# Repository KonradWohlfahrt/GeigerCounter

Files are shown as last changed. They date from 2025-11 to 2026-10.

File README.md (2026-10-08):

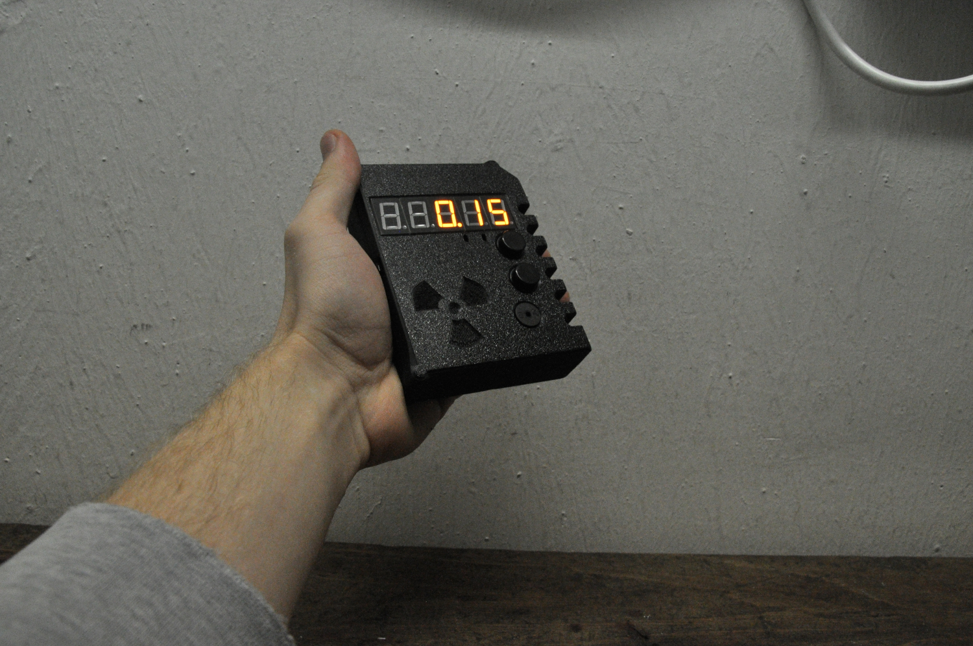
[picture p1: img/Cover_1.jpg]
Cover


# DIY Geiger Counter
This project is a fully functional DIY Geiger counter built around an M4011 Geiger–Müller tube, a custom two-board PCB design, and a retro-style five-digit seven-segment display. It’s portable, battery-powered and easy to build yourself.
The device measures radiation in µS/h, cpm, and raw counts, with settings stored in EEPROM. Navigation is handled by two buttons, and the counter provides both visual and audible feedback for detected radiation pulses. The project includes a 3D-printed housing with optional decorative elements.  
All PCBs and the stencil for this project were fabricated by [PCBWay](https://www.pcbway.com/), whose quality and service helped make the build smooth and enjoyable.  
This repository includes schematics, PCB files, firmware, STL files, and documentation so you can build your own portable Geiger Counter from scratch. You can find the full blog on Instructables: [DIY Geiger Counter](https://www.instructables.com/DIY-Geiger-Counter/)

**NOTE:**  
Version 3 of the main PCB is planned to address low-voltage limitations of the MT3608 boost converter. Version 2 users are encouraged to add a 100 µF capacitor across 5V and GND for improved stability.

***
# FEATURES
- Detects radiation using an M4011 Geiger-Müller tube
- Displays measurements in µS/h, cpm, or counts
- Simple navigation using two buttons: switch modes, reset counts, and access settings
- Configurable options saved in EEPROM: battery type, sound, and LED indicators
- Retro-inspired five-digit seven-segment display powered by two AA batteries

***
# PROGRAMMING
Programmed with the Arduino IDE and [MiniCore board manager](https://mcudude.github.io/MiniCore/package_MCUdude_MiniCore_index.json). No external library is required, everything is included in the sketch!

***
# ELECTRIC COMPONENTS - HIGH VOLTAGE CIRCUIT:
| Component | Amount | Silkscreen label |
|:---|:---:|---:|
| 1nF | 1 | C1 |
| 10nF | 2 | C2,C3 |
| 220pF | 2 | C4,C5 |
| 1N914 | 1 | D1 |
| 1N4937 | 1 | D2 |
| 5x20 Fuse Clip | 2 | J1-J4 |
| 5P-2.54 Header | 2 | J5,J6 |
| 10mH Inductor | 1 | L1 |
| 2N3904 | 2 | Q1,Q3 |
| FJN3303 | 1 | Q2 |
| 220k | 1 | R1 |
| 1k | 1 | R2 |
| 330r | 1 | R3 |
| 100k | 2 | R4,R9 |
| 8.2r | 1 | R5 |
| 10r potentiometer | 1 | R6 |
| 4.7M | 1 | R7 |
| 22k | 1 | R8 |
| 10k | 1 | R10 |
| TLC555 | 1 | U1 |
| M4011/J302/SI-3BG | 1 | - |

***
# ELECTRIC COMPONENTS - MAIN BOARD V3 CIRCUIT:
| Component | Amount | Silkscreen label |
|:---|:---:|---:|
| BH-AA-A5BJ012 | 2 | B1,B2 |
| Passive Buzzer 12x9.5 | 1 | BUZ1 |
| 22uF 0805 | 2 | C1,C2 |
| 100nF 0805 | 8 | C3-C6,C11-C13,C18 |
| 22pF 0805 | 2 | C7,C8 |
| 10uF 0805 | 1 | C9 |
| 1uF 0805 | 2 | C10,C17 |
| 100pF 0805 | 2 | C14,C15 |
| 100uF 1206 | 1 | C16 |
| 6P (2x3) 2.54 ICSP Header (optional) | 1 | H1 |
| 5P-2.54 Header | 2 | H3,H4 |
| Switch 12x12 & Round Button Cover | 2 | KEY1,KEY2 |
| 4.7uH 3015 | 1 | L1 |
| 5161BY Seven Segment Digit | 5 | LED1-LED5 |
| 0805 LED red | 2 | LED6,LED8 |
| 0805 LED green | 1 | LED7 |
| MMBT2222A | 3 | Q1-Q3 |
| 976k | 1 | R1 |
| 309k | 1 | R2 |
| 10k | 3 | R3,R9,R10 |
| 220r | 3 | R4,R12,R14 |
| 1k | 3 | R5,R11,R13 |
| 33r | 1 | R6 |
| 1.2k | 1 | R7 |
| 680r | 1 | R8 |
| SKF14L3 | 1 | SW1 |
| Switch SMD 3x6 | 1 | SW2 |
| MCP1640CT SOT-23-6 | 1 | U1 |
| ATmega328P | 1 | U2 |
| TM1637 | 1 | U3 |
| 8Mhz/16Mhz 3225 crystal | 1 | X1 |

***
# ELECTRIC COMPONENTS - MAIN BOARD V2 CIRCUIT:
| Component | Amount | Silkscreen label |
|:---|:---:|---:|
| BH-AA-A5BJ012 | 2 | B1,B2 |
| Passive Buzzer 12x9.5 | 1 | BUZ1 |
| 22uF | 2 | C1,C2 |
| 100nF | 6 | C3-C5,C10-C12 |
| 22pF | 2 | C6,C7 |
| 10uF | 1 | C8 |
| 1uF | 1 | C9 |
| 100pF | 2 | C13,C14 |
| SS34 | 1 | D1 |
| 6P (2x3) 2.54 ICSP Header (optional) | 1 | H1 |
| 5P-2.54 Header | 2 | H3,H4 |
| Switch 12x12 & Round Button Cover | 2 | KEY1,KEY2 |
| 22uH | 1 | L1 |
| 5161BY Seven Segment Digit | 5 | LED1-LED5 |
| 0805 LED red | 2 | LED6,LED8 |
| 0805 LED green | 1 | LED7 |
| MMBT2222A | 3 | Q1-Q3 |
| 220k | 1 | R1 |
| 30k | 1 | R2 |
| 10k | 3 | R3,R9,R10 |
| 220r | 3 | R4,R12,R14 |
| 1k | 3 | R5,R11,R13 |
| 33r | 1 | R6 |
| 1.2k | 1 | R7 |
| 680r | 1 | R8 |
| SKF14L3 | 1 | SW1 |
| Switch SMD 3x6 | 1 | SW2 |
| MT3608 | 1 | U1 |
| ATmega328P | 1 | U2 |
| TM1637 | 1 | U3 |
| 8Mhz/16Mhz 3225 crystal | 1 | X1 |

***
# Housing Components:
| Component | Amount |
|:---|---:|
| M3 Threaded Heat Insert: 5x4,2mm (height x outer diameter) | 8 |
| M3x6mm | 2 |
| M3x18mm | 3 |
| M3x20mm | 3 |
| M3 Threaded Heat Insert: 3x4,2mm (height x outer diameter) | 1 |
| M3x4mm | 1 |
| AA Battery | 2 |

***
# GALLERY
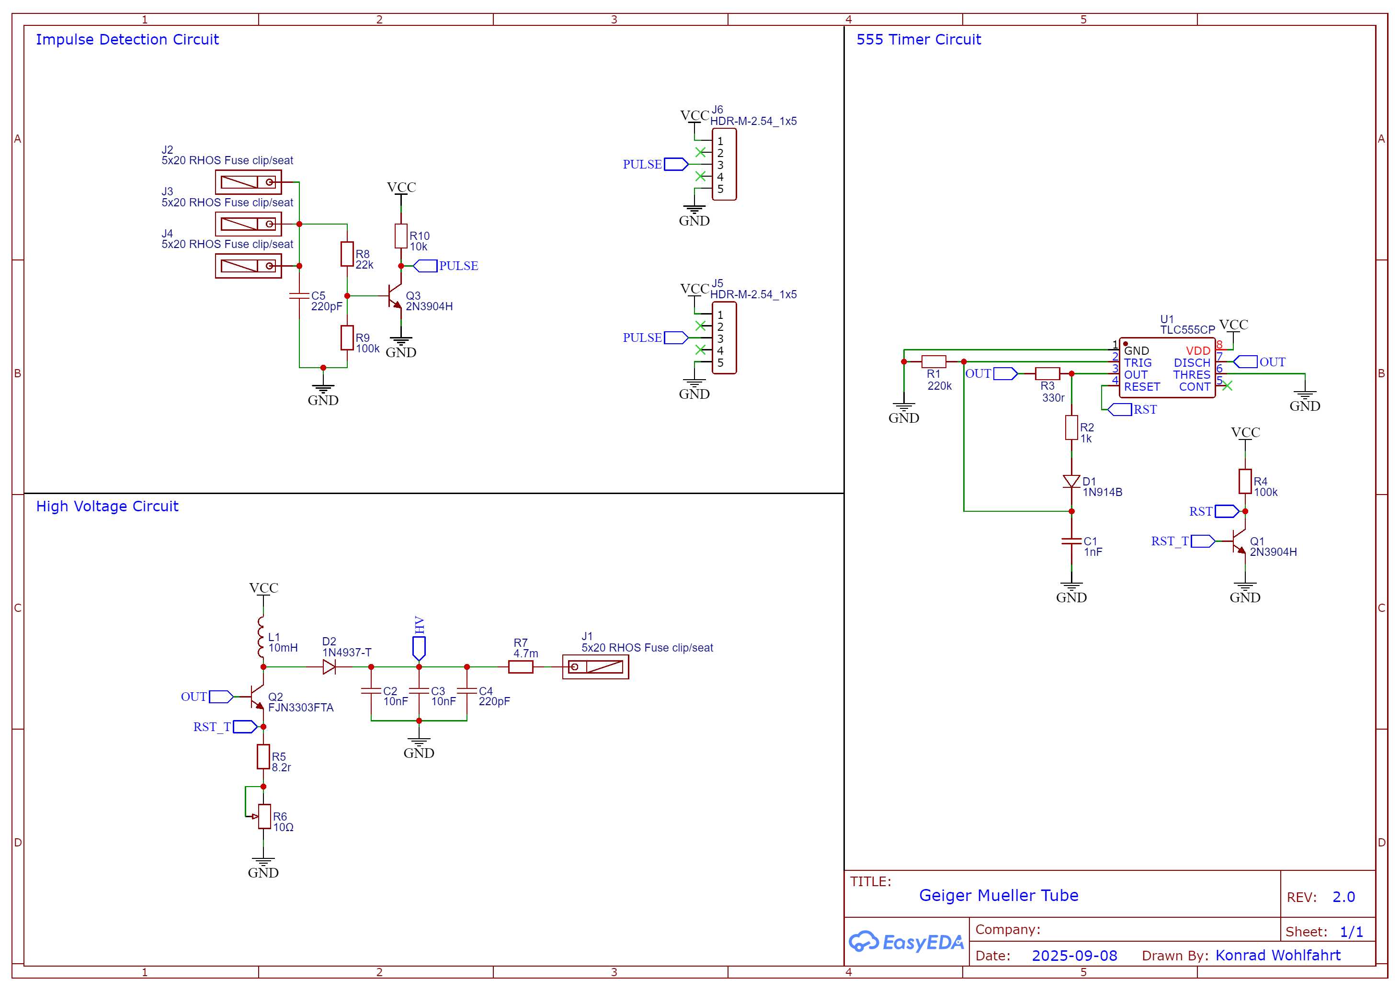
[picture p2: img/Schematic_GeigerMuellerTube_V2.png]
Schematic HV Circuit

_Schematic of the high voltage PCB_  
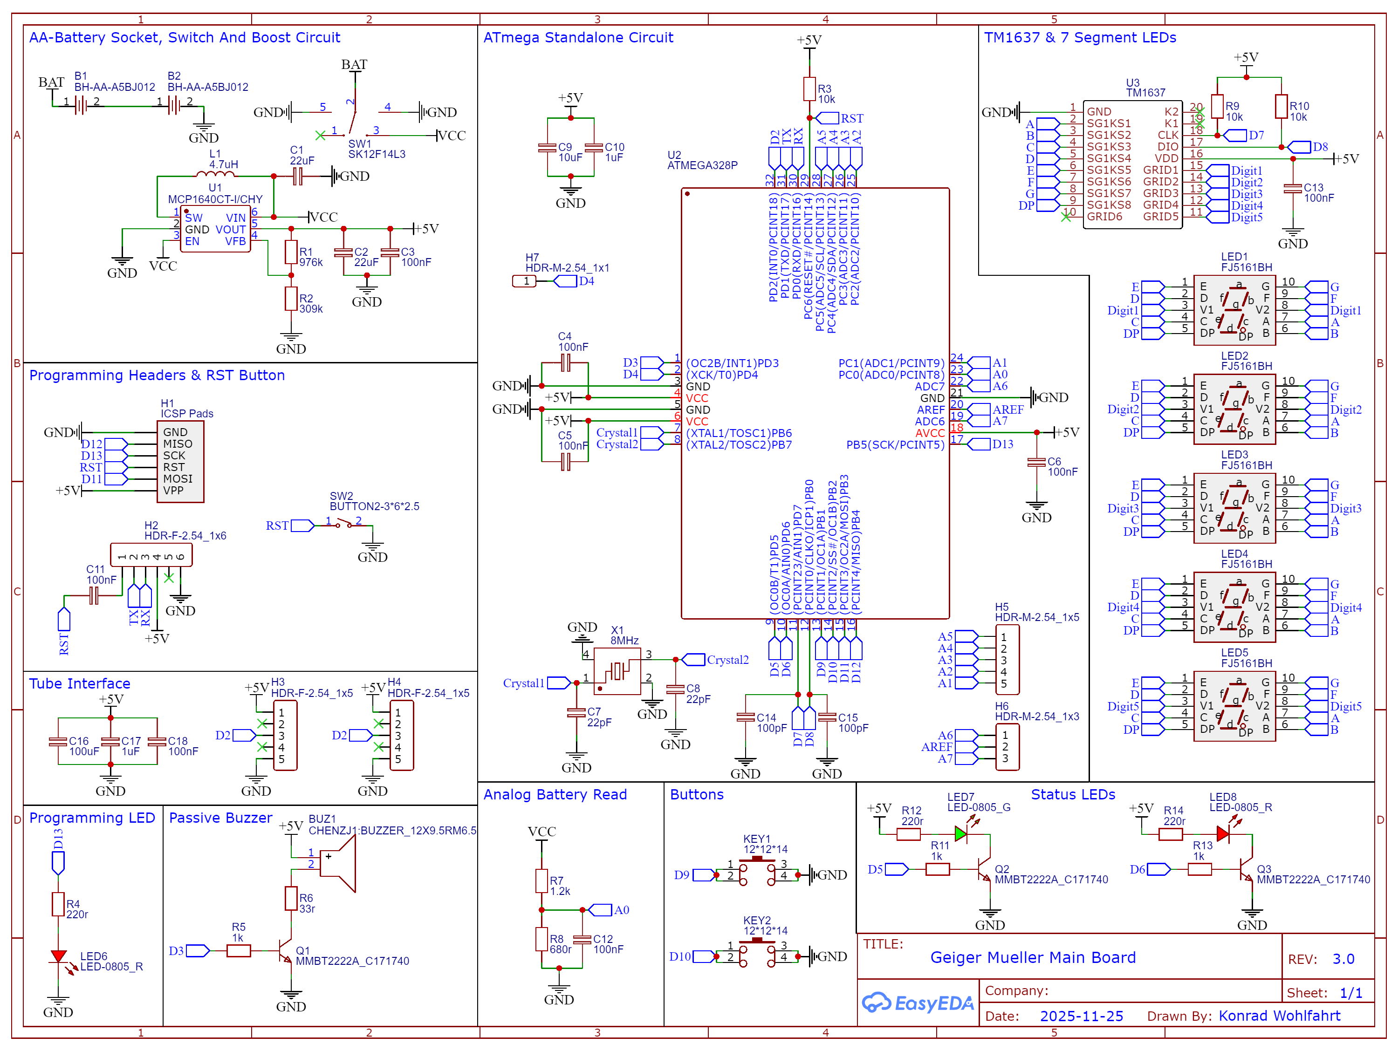
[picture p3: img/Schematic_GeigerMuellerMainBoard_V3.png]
Schematic MainBoard

_Schematic of the main board (V3)_  
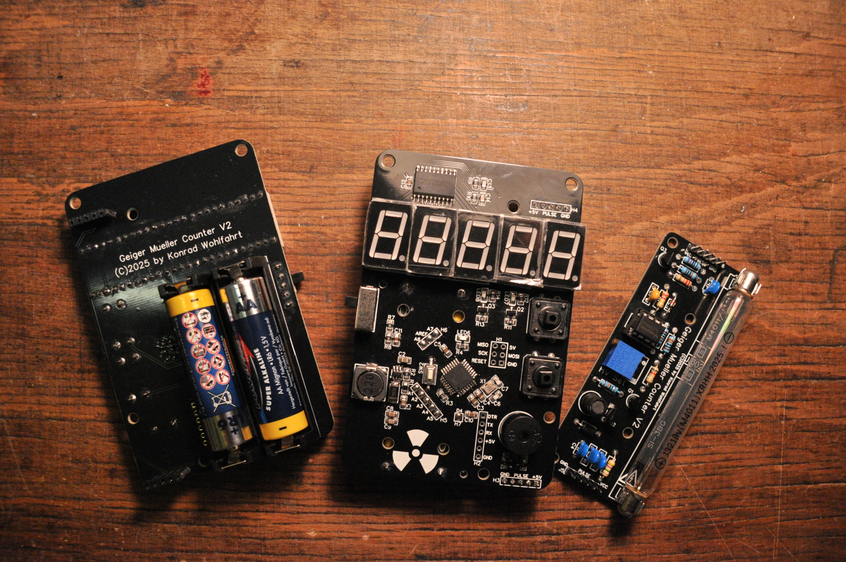
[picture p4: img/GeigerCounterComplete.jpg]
Complete Geiger Counter

_Complete Geiger Counter Build_  
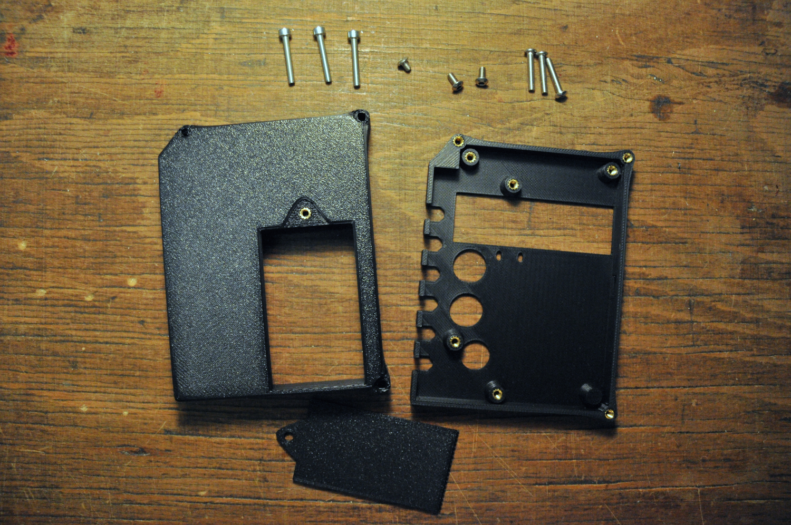
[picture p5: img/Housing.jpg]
Housing

_3D printed housing_  

***
# NAVIGATION
The Geiger counter is controlled with two buttons. The **lower button** cycles through the measurement modes: µS/h (microsieverts per hour), cpm (counts per minute), and total counts. The **upper button** resets the counts to zero, which also restarts the µS/h and cpm readings. Holding down the **upper button** takes you into the settings menu. Once inside, the **lower button** cycles through the available options, while the **upper button** changes the selected setting. A long press exits the menu and returns to the main display.  
The configurable options include battery type (Alkaline, NiMH, or Lithium), sound (On or Off), and LED indicators (On or Off — the warning LED always remains on). All settings are saved in EEPROM, so they remain even after the counter is powered off.  

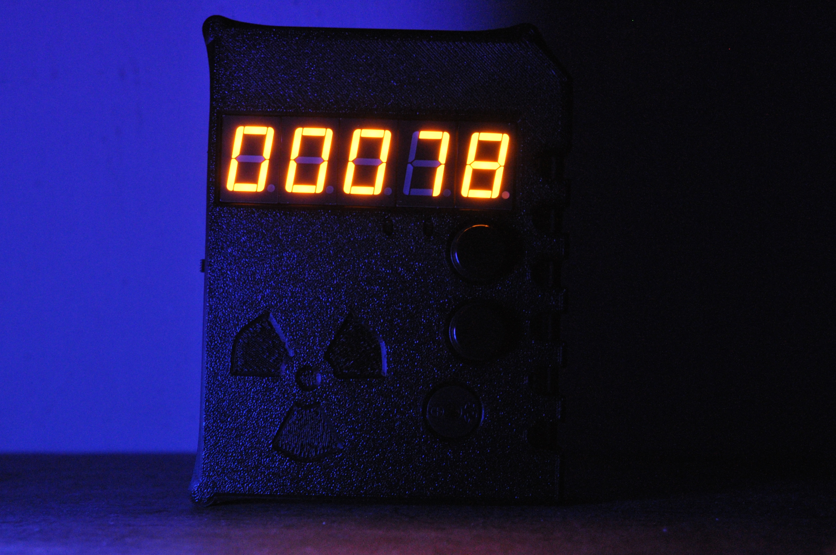
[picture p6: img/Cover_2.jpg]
Geiger Counter


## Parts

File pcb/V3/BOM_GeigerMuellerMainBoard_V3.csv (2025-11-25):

ID | Name | Designator | Footprint | Quantity | Manufacturer Part | Manufacturer | Supplier | Supplier Part | Price | Pins | 3DModel | Contributor | JLCPCB Part Class | image | link
1 | BH-AA-A5BJ012 | B1,B2 | BAT-TH_BH-AA-A5BJ012 | 2 | BH-AA-A5BJ012 | MYOUNG(美阳) | LCSC | C5290180 | 0.576 | 2 | BAT-TH_BH-AA-A5BJ012 | lcsc | Extended Part |  | https://atta.szlcsc.com/upload/public/pdf/source/20221129/39BBE9EF152B2F12CD5AEA2F9E97207C.pdf
2 | MCP1640CT-I/CHY | U1 | SOT-23-6_L2.9-W1.6-P0.95-LS2.8-BR | 1 | MCP1640CT-I/CHY | MICROCHIP(美国微芯) | LCSC | C511326 | 0.815 | 6 | SOT-23-6_L2.9-W1.6-H1.5-LS2.8-P0.95 | LCSC | Extended Part |  | https://item.szlcsc.com/169042.html
3 | 309k | R2 | R0805 | 1 |  |  |  |  |  | 2 | R0805_L2.0-W1.3-H0.6 | LCEDA_Lib |  |  | https://item.szlcsc.com/142685.html
4 | 976k | R1 | R0805 | 1 |  |  |  |  |  | 2 | R0805_L2.0-W1.3-H0.6 | LCEDA_Lib |  |  | https://item.szlcsc.com/142685.html
5 | 4.7uH | L1 | IND-SMD_L3.0-W3.0-1 | 1 | ANR3015T4R7M | APV(爱普微) | LCSC | C7427089 | 0.034 | 2 | IND-SMD_L3.0-W3.0-1 | lcsc | Extended Part |  | https://atta.szlcsc.com/upload/public/pdf/source/20210916/41BC1D61F1B8031533859732D09FE353.pdf
6 | 100uF | C16 | C1206 | 1 |  |  |  |  |  | 2 | C1206_L3.2-W1.6-H1.3 | LCEDA_Lib |  |  | https://item.szlcsc.com/89171.html
7 | 100nF | C18,C3,C4,C5,C6,C11,C12,C13 | C0805 | 8 |  |  |  |  |  | 2 | C0805_L2.0-W1.3-H1.3 | LCEDA_Lib |  |  | https://item.szlcsc.com/373011.html
8 | 1uF | C17,C10 | C0805 | 2 |  |  |  |  |  | 2 | C0805_L2.0-W1.3-H1.3 | LCEDA_Lib |  |  | https://item.szlcsc.com/373011.html
9 | 22uF | C2,C1 | C0805 | 2 |  |  |  |  |  | 2 | C0805_L2.0-W1.3-H1.3 | LCEDA_Lib |  |  | https://item.szlcsc.com/373011.html
10 | CHENZJ1:BUZZER_12X9.5RM6.5 | BUZ1 | BUZ-TH_BD12.0-P6.50-D0.6_SEA-1285F | 1 | chenzj1:Buzzer_12x9.5RM6.5 | null | LCSC | C9900008742 |  | 2 | BUZ-TH_BD12.0-P6.50-D0.6_SEA-1285F | LCSC | Extended Part |  | https://atta.szlcsc.com/upload/public/pdf/source/20211008/4CBF24C00656D781101954279FAE3DDF.pdf
11 | 22pF | C7,C8 | C0805 | 2 |  |  |  |  |  | 2 | C0805_L2.0-W1.3-H1.3 | LCEDA_Lib |  |  | https://item.szlcsc.com/373011.html
12 | 10uF | C9 | C0805 | 1 |  |  |  |  |  | 2 | C0805_L2.0-W1.3-H1.3 | LCEDA_Lib |  |  | https://item.szlcsc.com/373011.html
13 | 100pF | C14,C15 | C0805 | 2 |  |  |  |  |  | 2 | C0805_L2.0-W1.3-H1.3 | LCEDA_Lib |  |  | https://item.szlcsc.com/373011.html
14 | ICSP Pads | H1 | ICSP | 1 |  |  |  |  |  | 6 |  | dreAn
15 | HDR-F-2.54_1x6 | H2 | HDR-F-2.54_1X6 | 1 |  |  | LCSC | C40877 | 0.071 | 6 | HDR-F-2.54_1x6 | LCEDA_Lib
16 | HDR-F-2.54_1x5 | H3,H4 | HDR-F-2.54_1X5 | 2 |  |  | LCSC | C50950 | 0.064 | 5 | HDR-F-2.54_1x5 | LCEDA_Lib
17 | HDR-M-2.54_1x5 | H5 | HDR-M-2.54_1X5 | 1 |  |  | LCSC | C358687 | 0.03 | 5 | HDR-M-2.54_1x5 | LCEDA_Lib
18 | HDR-M-2.54_1x3 | H6 | HDR-M-2.54_1X3 | 1 |  |  | LCSC | C180248 | 0.187 | 3 | HDR-M-2.54_1x3 | LCEDA_Lib
19 | HDR-M-2.54_1x1 | H7 | HDR-M-2.54_1X1 | 1 |  |  | LCSC | C81276 | 0.008 | 1 | HDR-M-2.54_1x1 | LCEDA_Lib
20 | 12*12*14 | KEY1,KEY2 | SW-TH_4P-L12.0-W12.0-P5.00-LS12.5_TC-1103XX | 2 | 12*12*14 | ReliaPro | LCSC | C27480 |  | 4 | SW-TH_4P-L12.0-W12.0-P5.00-LS12.5_TC-1103XX | lcsc | Extended Part |  | https://item.szlcsc.com/487764.html?ref=editor&logined=true
21 | FJ5161BH | LED1,LED2,LED3,LED4,LED5 | LED-SEG-TH_FJ5161BH | 5 | FJ5161BH | 志浩 | LCSC | C8092 | 0.199 | 10 | LED-SEG-TH_10P-L12.6-W19.0-H8.0-P2.54-S15.24 | 立创EDA官方封装库 | Extended Part |  | https://item.szlcsc.com/8574.html
22 | LED-0805_R | LED6,LED8 | LED0805_RED | 2 | 17-21SURC/S530-A3/TR8 | EVERLIGHT(台湾亿光) |  | C72037 | 0.025 | 2 | LED0805_Red | LCEDA_Lib
23 | LED-0805_G | LED7 | LED0805_GREEN | 1 | NCD0805G1 | 国星光电 |  | C84260 | 0.02 | 2 | LED0805_Green | LCEDA_Lib
24 | MMBT2222A_C171740 | Q1,Q2,Q3 | SOT-23-3_L2.9-W1.3-P1.90-LS2.4-BR | 3 | MMBT2222A | SHIKUES(时科) | LCSC | C171740 | 0.013 | 3 | SOT-23-3P_L2.9-W1.3-H1.0-LS2.4-P0.95 | 立创EDA官方封装库 | Extended Part |  | https://www.diodes.com/assets/Package-Files/SOT23.pdf
25 | 10k | R3,R9,R10 | R0805 | 3 |  |  |  |  |  | 2 | R0805_L2.0-W1.3-H0.6 | LCEDA_Lib |  |  | https://item.szlcsc.com/142685.html
26 | 220r | R4,R12,R14 | R0805 | 3 |  |  |  |  |  | 2 | R0805_L2.0-W1.3-H0.6 | LCEDA_Lib |  |  | https://item.szlcsc.com/142685.html
27 | 1k | R5,R11,R13 | R0805 | 3 |  |  |  |  |  | 2 | R0805_L2.0-W1.3-H0.6 | LCEDA_Lib |  |  | https://item.szlcsc.com/142685.html
28 | 100r | R6 | R0805 | 1 |  |  |  |  |  | 2 | R0805_L2.0-W1.3-H0.6 | LCEDA_Lib |  |  | https://item.szlcsc.com/142685.html
29 | 1.2k | R7 | R0805 | 1 |  |  |  |  |  | 2 | R0805_L2.0-W1.3-H0.6 | LCEDA_Lib |  |  | https://item.szlcsc.com/142685.html
30 | 680r | R8 | R0805 | 1 |  |  |  |  |  | 2 | R0805_L2.0-W1.3-H0.6 | LCEDA_Lib |  |  | https://item.szlcsc.com/142685.html
31 | SK12F14L3 | SW1 | SW-TH_SK12F14G5 | 1 | SK12F14L3 | XKB Connection(中国星坤) | LCSC | C5146272 | 0.026 | 5 | SW-TH_SK12F14G5 | lcsc |  |  | https://atta.szlcsc.com/upload/public/pdf/source/20210820/9527CA5F223E7A23E59122DED0FC191C.pdf
32 | BUTTON2-3*6*2.5 | SW2 | SW-SMD_L6.0-W3.7-LS8.0 | 1 | BUTTON2-3*6*2.5 | null | LCSC | C9900009018 |  | 2 | SW-SMD_L6.0-W3.7-LS8.0 | LCSC | Extended Part |  | https://item.szlcsc.com/1054610.html
33 | ATMEGA328P | U2 | LQFP-32_L7.0-W7.0-P0.80-LS9.0-TL | 1 | ATmega328P | null | LCSC | C9900009806 |  | 32 | LQFP-32_L7.0-W7.0-H1.4-LS9.0-P0.80 | LCSC | Extended Part |  | https://item.szlcsc.com/179025.html
34 | TM1637 | U3 | SOP-20_L12.8-W7.5-P1.27-LS10.4-BL | 1 | TM1637 | TM(天微) | LCSC | C20001 | 0.217 | 20 | SOP-20_L12.8-W7.5-H2.5-LS10.4-P1.27 | Tinkerforge | Extended Part |  | https://item.szlcsc.com/365354.html
35 | 8MHz | X1 | CRYSTAL-SMD_4P-L3.2-W2.5-BL | 1 | L327S080D11L | Lucki(蓝晶) | LCSC | C5261255 | 0.151 | 4 | CRYSTAL-SMD_4P-L3.2-W2.5-BL | lcsc | Extended Part |  | https://item.szlcsc.com/15866.html

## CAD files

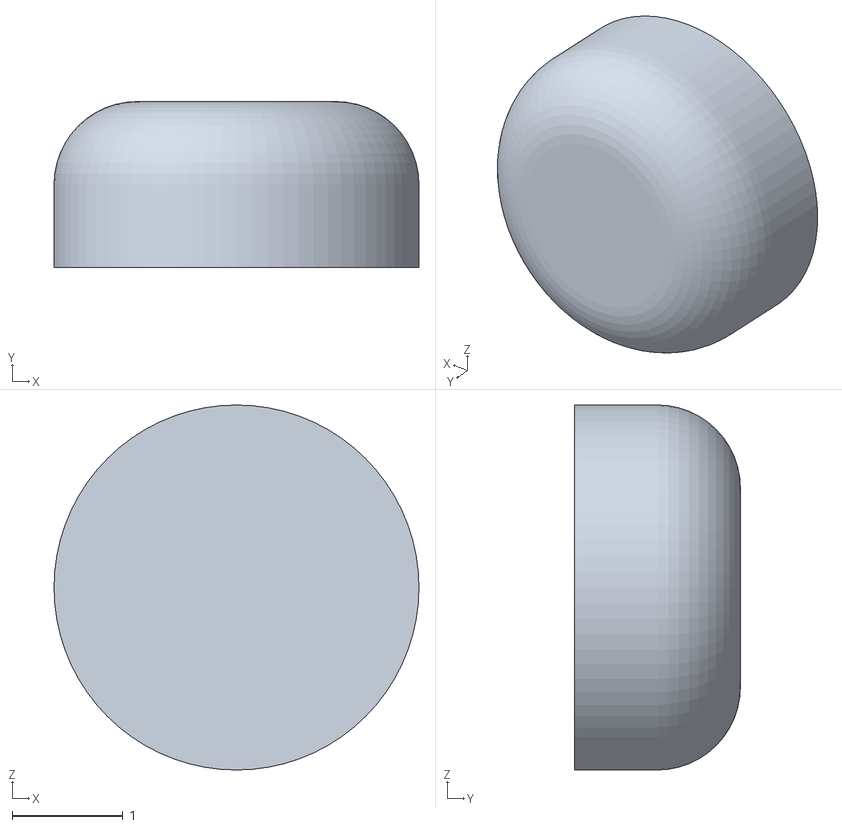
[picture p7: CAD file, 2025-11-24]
cad/RadioactiveSignInner.stl
3.30 x 1.50 x 3.30

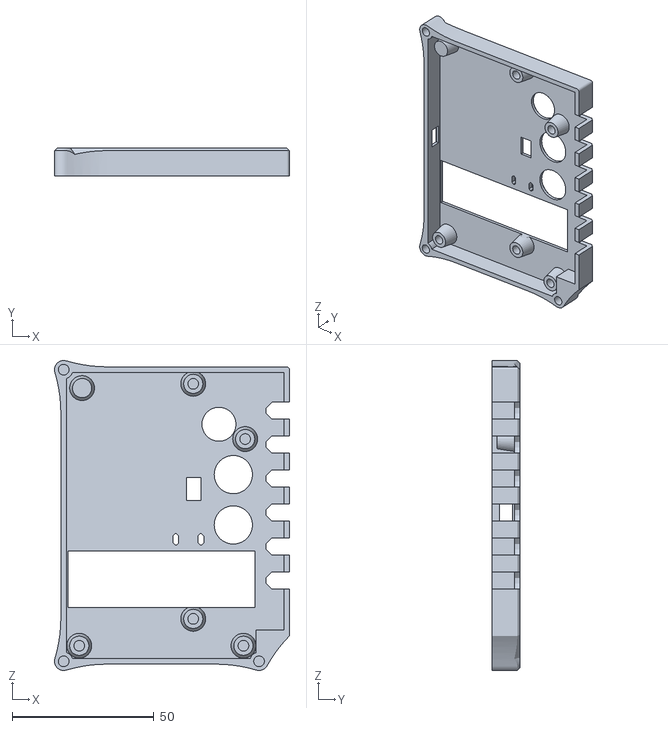
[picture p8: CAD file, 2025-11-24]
cad/Geiger Counter Top.stl
83.0 x 10.0 x 109.5

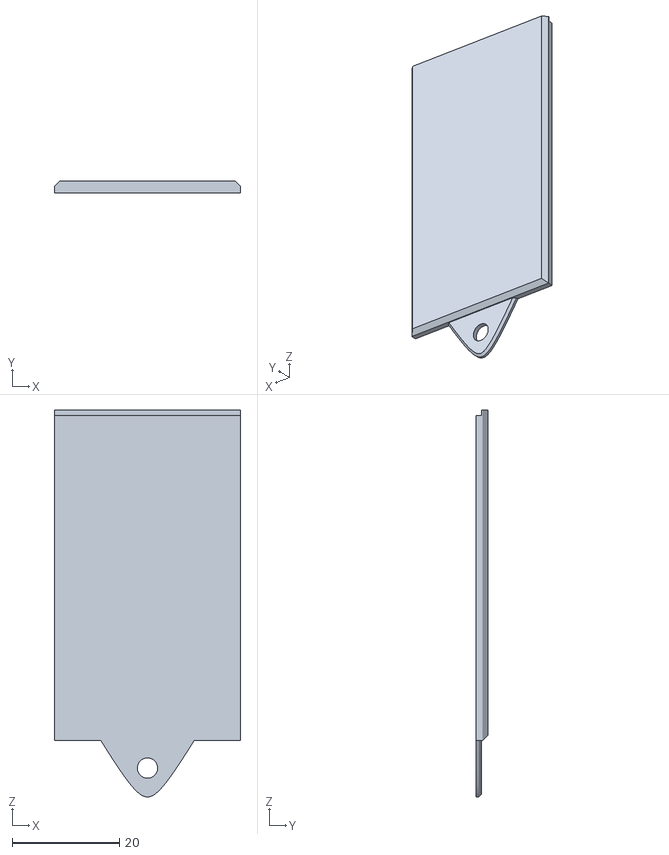
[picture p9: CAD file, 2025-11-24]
cad/Geiger Counter Battery Lid.stl
34.8 x 2.20 x 72.3

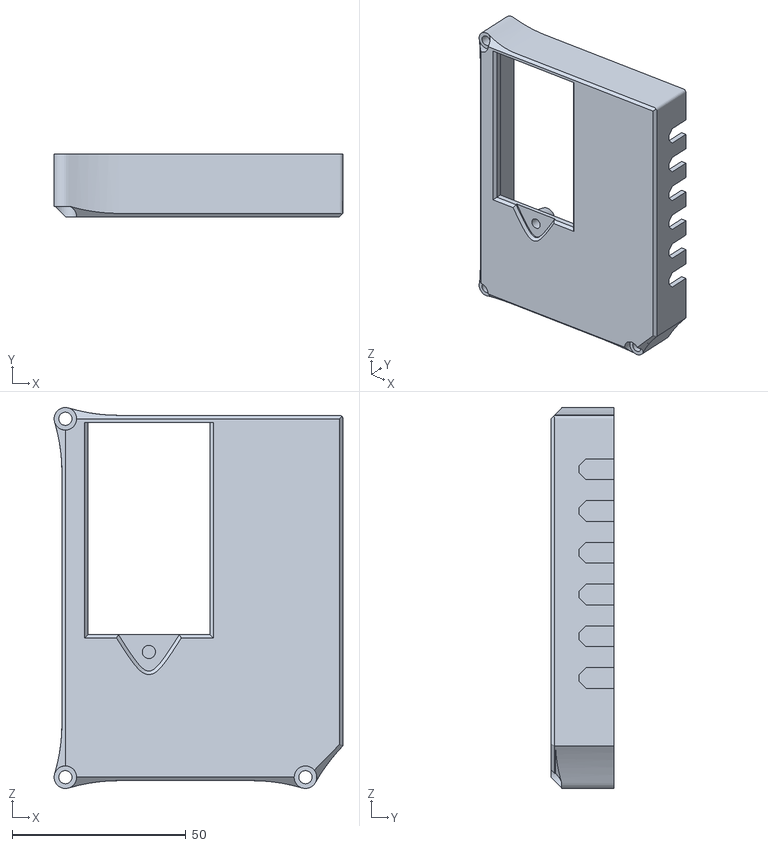
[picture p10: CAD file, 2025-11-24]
cad/Geiger Counter Bottom.stl
83.0 x 18.0 x 109.5

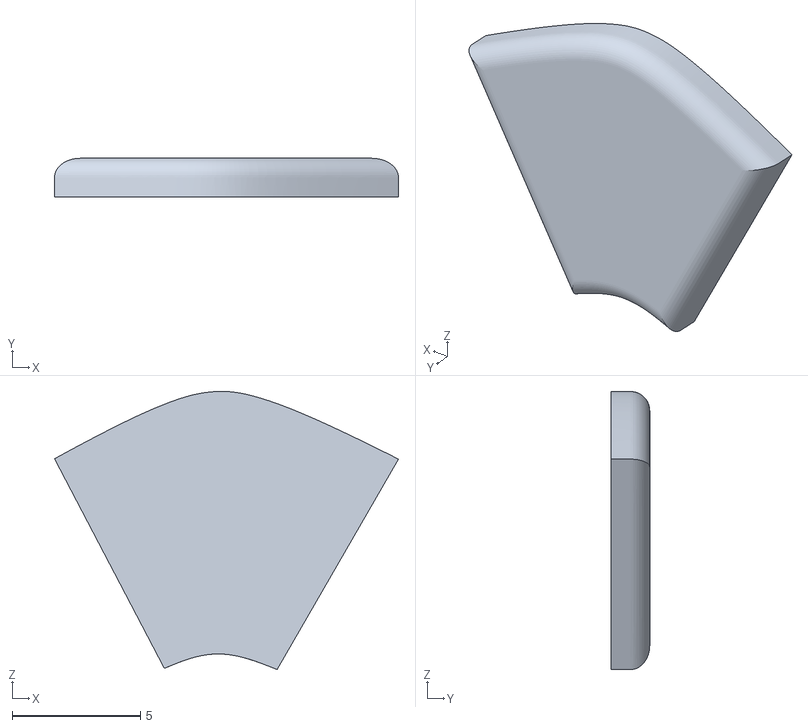
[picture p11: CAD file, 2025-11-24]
cad/RadioactiveSignOuter.stl
13.4 x 1.50 x 10.8

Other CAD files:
cad/Geiger Counter Top without ICSP.stl

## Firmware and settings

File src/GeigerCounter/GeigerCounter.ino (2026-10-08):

#include "preferences.h"

volatile bool pulseEvent = false;
volatile uint32_t counts = 0;
uint32_t resetTimestamp = 0;
float cpm;
float uSievert;

uint32_t infoTimestamp;
bool showInfo = false;

uint32_t lastRefresh;
uint8_t displayIndex = 2; // 0=uS/h, 1=cpm, 2=total counts (will select next mode at start)

bool settings = false;
uint8_t settingsIndex = 0; // 0=battery, 1=sound, 2=leds
bool hasSound = true;
bool ledsOn = true;
const char batteryChars[3][5] = {
  { 'a', 'l', 'k', 'a', 'l' },
  { 'n', 'i', 'm', 'h', 0 },
  { 'l', 'i', 't', 'h', 'i' }
};


void setup() 
{
  // set up pins
  analogReference(INTERNAL);
  pinMode(BATTERY_PIN, INPUT);

  pinMode(PULSE_PIN, INPUT);

  pinMode(BUTTON_UP, INPUT_PULLUP);
  pinMode(BUTTON_DOWN, INPUT_PULLUP);

  pinMode(BUZZER_PIN, OUTPUT);

  pinMode(LED_RED, OUTPUT);
  pinMode(LED_GREEN, OUTPUT);

  // show boot animation, set voltage stabilize
  display.clear();
  display.setInt(88888); // all segments on
  for (uint8_t i = 0; i < 8; i++)
  {
    analogWrite(LED_RED, 255 / 8 * i);
    analogWrite(LED_GREEN, 255 / 8 * i);

    display.setBrightness(i);
    display.show();
    delay(50);
  }
  analogWrite(LED_RED, 0);
  analogWrite(LED_GREEN, 0);

  // read EEPROM
  _selectedBattery = constrain(EEPROM.read(0), 0, 2);
  hasSound = constrain(EEPROM.read(1), 0, 1);
  ledsOn = constrain(EEPROM.read(2), 0, 1);

  // show battery voltage at start
  updateBrightness();
  display.setInt(batteryPercent(), true);
  display.move(2);
  display.setDigit(4, 0b00011011);
  display.show();
  delay(2000);

  resetCounts();
  nextMode();

  attachInterrupt(digitalPinToInterrupt(PULSE_PIN), pulseInterrupt, FALLING);
}
void loop() 
{
  if (btnUp())
  {
    uint32_t started = millis();
    bool longPress = false;
    while (btnUp())
    {
      updateScreen(false);
      if (!longPress && isTimestamp(started, LONG_PRESS))
      {
        longPress = true;
        settings = !settings;
        settingsIndex = 0;
      }
    }
    
    if (!longPress)
    {
      if (settings)
      {
        if (settingsIndex == 0)
          _selectedBattery = (_selectedBattery + 1) % 3;
        else if (settingsIndex == 1)
          hasSound = !hasSound;
        else
          ledsOn = !ledsOn;
      }
      else
        resetCounts();
    }
    else if (!settings)
      saveEEPROM();
    updateScreen(true);
  }

  if (btnDown())
  {
    while (btnDown()) updateScreen(false);
    
    nextMode();
    updateScreen(true);
  }

  if (showInfo && isTimestamp(infoTimestamp, 750))
  {
    showInfo = false;
    updateScreen(true);
  }
  else
    updateScreen(false);
}

void pulseInterrupt() 
{
  counts++;
  pulseEvent = true;
  if (hasSound)
    click();
}
void updateScreen(bool force)
{
  updateWarnLED();

  if (settings)
  {
    display.clear();
    if (settingsIndex == 0)
    {
      for (uint8_t i = 0; i < 5; i++)
        display.setDigit(i, display.getCharacter(batteryChars[_selectedBattery][i]));
    }
    else if (settingsIndex == 1)
    {
      display.setDigit(0, display.getNumber(5));
      if (hasSound)
      {
        display.setDigit(3, display.getCharacter('o'));
        display.setDigit(4, display.getCharacter('n'));
      }
      else
      {
        display.setDigit(2, display.getCharacter('o'));
        display.setDigit(3, display.getCharacter('f'));
        display.setDigit(4, display.getCharacter('f'));
      }
    }
    else
    {
      display.setDigit(0, display.getCharacter('l'));
      if (ledsOn)
      {
        display.setDigit(3, display.getCharacter('o'));
        display.setDigit(4, display.getCharacter('n'));
      }
      else
      {
        display.setDigit(2, display.getCharacter('o'));
        display.setDigit(3, display.getCharacter('f'));
        display.setDigit(4, display.getCharacter('f'));
      }
    }
    display.show();
    return;
  }

  if (showInfo)
  {
    display.clear();
    if (displayIndex == 0)
    {
      display.setDigit(0, display.getCharacter('u'));
      display.setDigit(1, display.getCharacter('5'));
      display.setDigit(2, display.getCharacter('/'));
      display.setDigit(3, display.getCharacter('h'));
    }
    else if (displayIndex == 1)
    {
      display.setDigit(0, display.getCharacter('c'));
      display.setDigit(1, display.getCharacter('p'));
      display.setDigit(2, display.getCharacter('m'));
    }
    else if (displayIndex == 2)
    {
      display.setDigit(0, display.getCharacter('c'));
      display.setDigit(1, display.getCharacter('o'));
      display.setDigit(2, display.getCharacter('u'));
      display.setDigit(3, display.getCharacter('n'));
      display.setDigit(4, display.getCharacter('t'));
    }
    display.show();
  }
  else
  {
    if (pulseEvent || force || isTimestamp(lastRefresh, 1000))
    {
      pulseEvent = false;
      cpm = counts / ((millis() - resetTimestamp) / 60000.0f);
      uSievert = cpm / TUBE_FACTOR;
      
      updateBrightness();
      if (displayIndex == 0)
        display.setFloat(uSievert);
      else if (displayIndex == 1)
        display.setFloat(cpm);
      else if (displayIndex == 2)
        display.setInt(counts % 100000, true);
      display.show();
    }
  }
}
void updateWarnLED()
{
  if (uSievert < 0.5f || (uSievert < 2.5f && !ledsOn))
  {
    analogWrite(LED_GREEN, 0);
    analogWrite(LED_RED, 0);
  }
  else if (uSievert < 1.0f && ledsOn)
  {
    analogWrite(LED_GREEN, 80);
    analogWrite(LED_RED, 0);
  }
  else if (uSievert < 2.5f && ledsOn)
  {
    analogWrite(LED_GREEN, 255);
    analogWrite(LED_RED, 0);
  }
  else if (uSievert < 5.0f)
  {
    analogWrite(LED_GREEN, 0);
    analogWrite(LED_RED, 255);
  }
  else if (uSievert < 10.0f)
  {
    analogWrite(LED_GREEN, 0);
    analogWrite(LED_RED, isInterval(1000) ? 255 : 0);
  }
  else if (uSievert < 100.0f)
  {
    analogWrite(LED_GREEN, 0);
    analogWrite(LED_RED, isInterval(500) ? 255 : 0);
  }
  else 
  {
    analogWrite(LED_GREEN, isInterval(250) ? 255 : 0);
    analogWrite(LED_RED, isInterval(250) ? 255 : 0);
  }
}
void updateBrightness()
{
  uint8_t p = batteryPercent();
  if (p < 50)
  {
    uint8_t newBrightness = (uint8_t)((7.0f / 50.0f) * p);
    if (newBrightness < display.getBrightness())
      display.setBrightness(newBrightness, false);
  }
  else
    display.setBrightness(7, false);
}

void nextMode()
{
  if (!settings)
  {
    displayIndex = (displayIndex + 1) % 3;
    showInfo = true;
    infoTimestamp = millis();
  }
  else
  {
    settingsIndex = (settingsIndex + 1) % 3;
  }
}
void saveEEPROM()
{
  EEPROM.update(0, _selectedBattery);
  EEPROM.update(1, hasSound ? 1 : 0);
  EEPROM.update(2, ledsOn ? 1 : 0);
}

void resetCounts()
{
  counts = 0;
  resetTimestamp = millis() - 5; // -5ms: avoid dividing by 0
}

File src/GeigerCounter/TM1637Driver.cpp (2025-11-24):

#include "Arduino.h"
#include "TM1637Driver.h"

#define DISPLAY_LENGTH 5

#define TM1637_WRITE_DELAY 100

#define TM1637_DATA_COMMAND 0x40
#define TM1637_DISPLAY_CONTROL_COMMAND 0x80 
#define TM1637_ADDRESS_COMMAND 0xC0


TM1637::TM1637(uint8_t pinDIO, uint8_t pinCLK)
{
  _pinDIO = pinDIO;
  _pinCLK = pinCLK;

  pinMode(pinCLK, INPUT);
  pinMode(pinDIO, INPUT);
	digitalWrite(pinCLK, LOW);
	digitalWrite(pinDIO, LOW);
}


void TM1637::setBrightness(uint8_t brightness, bool refresh)
{
  _brightness = brightness & 0x07;
  if (refresh)
    show();
}
uint8_t TM1637::getBrightness()
{
  return _brightness;
}


void TM1637::enableDisplay(bool enable, bool refresh)
{
  _enabled = enable;
  if (refresh)
    show();
}
bool TM1637::enabled()
{
  return _enabled;
}


void TM1637::clear()
{
  for (int i = 0; i < DISPLAY_LENGTH; i++)
    _displayBuffer[i] = 0x00;
}
void TM1637::move(int8_t shift)
{
  if (shift == 0)
    return;

  if (shift > 0)
  {
    for (int8_t i = 0; i < DISPLAY_LENGTH; i++)
    {
      int8_t newDigit = i + shift;
      if (digitInRange(newDigit))
        _displayBuffer[i] = _displayBuffer[newDigit];
      else
        _displayBuffer[i] = 0x00;
    }
  }
  else
  {
    for (int8_t i = DISPLAY_LENGTH - 1; i >= 0; i--)
    {
      int8_t newDigit = i + shift;
      if (digitInRange(newDigit))
        _displayBuffer[i] = _displayBuffer[newDigit];
      else
        _displayBuffer[i] = 0x00;
    }
  }
}
void TM1637::setSegments(const uint8_t* segments)
{
  uint8_t size = sizeof(segments) / sizeof(segments[0]);
  for (uint8_t i = 0; i < DISPLAY_LENGTH; i++)
  {
    if (i <= size)
      _displayBuffer[i] = segments[i];
    else
      _displayBuffer[i] = 0x00;
  }
}
void TM1637::setInt(int32_t number, bool leadZeros) 
{
  setNumber(number, leadZeros);
}
void TM1637::setFloat(float number, bool leadZeros, uint8_t decimalPlaces)
{
  bool negativ = number < 0;
  if (negativ)
    number = -number;

  uint8_t exp = decimalPlaces;
  for (uint8_t i = 1; i <= decimalPlaces + (negativ ? 1 : 0); i++)
  {
    if (number >= pow(10, DISPLAY_LENGTH - i))
      exp--;
  }

  int32_t n = (int32_t)(number * pow(10, exp) + 0.5f);
  setNumber(n * (negativ ? -1 : 1), leadZeros, DISPLAY_LENGTH - 1 - exp);
}
void TM1637::setNumber(int32_t number, bool leadZeros, uint8_t dot)
{
  bool negativ = number < 0;
  if (negativ)
    number = -number;

  bool begun = false;
  for (uint8_t i = 0; i < DISPLAY_LENGTH; i++)
  {
    uint8_t index = DISPLAY_LENGTH - 1 - i;
    uint32_t divisor = (uint32_t)(pow(10, index) + 0.5f);
    uint8_t digit = (uint8_t)((number / divisor) % 10);

    if (digit != 0 || begun)
    {
      begun = true;
      _displayBuffer[i] = _numbers[digit];
    }
    else
    {
      if (negativ)
      {
        divisor = (uint32_t)(pow(10, index - 1) + 0.5f);
        uint8_t nextDigit = (uint8_t)((number / divisor) % 10);
        if (nextDigit != 0 || i == dot - 1)
        {
          negativ = false;
          _displayBuffer[i] = _segments[6];
          continue;
        }
      }

      if (leadZeros || i == DISPLAY_LENGTH - 1 || i >= dot)
        _displayBuffer[i] = _numbers[0];
      else
        _displayBuffer[i] = 0x00;
    }

    if (i == dot)
      _displayBuffer[i] |= _segments[7];
  }
}
void TM1637::setDigit(uint8_t index, uint8_t digit)
{
  if (digitInRange(index))
    _displayBuffer[index] = digit;
}
uint8_t TM1637::getDigit(uint8_t index)
{
  if (digitInRange(index))
    return _displayBuffer[index];
  return 0x00;
}
void TM1637::setDigitSegment(uint8_t digitIndex, uint8_t segmentIndex, bool value)
{
  if (!digitInRange(digitIndex) || !segmentInRange(segmentIndex))
    return;
  
  if (value)
    _displayBuffer[digitIndex] = _displayBuffer[digitIndex] | _segments[segmentIndex];
  else
    _displayBuffer[digitIndex] = _displayBuffer[digitIndex] & (~_segments[segmentIndex]);
}
bool TM1637::getDigitSegment(uint8_t digitIndex, uint8_t segmentIndex)
{
  if (!digitInRange(digitIndex) || !segmentInRange(segmentIndex))
    return false;
  return (_displayBuffer[digitIndex] & _segments[segmentIndex]) != 0;
}


void TM1637::show()
{
  start();
  writeByte(TM1637_DATA_COMMAND); // indicate data write to display register
  stop();

  start();
  writeByte(TM1637_ADDRESS_COMMAND); // write display address command (start: C0H)
	for (uint8_t i = 0; i < DISPLAY_LENGTH; i++)
	  writeByte(_displayBuffer[i]); // write each digit data
	stop();

  start();
  writeByte(TM1637_DISPLAY_CONTROL_COMMAND | _brightness | (_enabled ? 0x08 : 0x00)); // write brightness & on/off
  stop();
}


uint8_t TM1637::getNumber(uint8_t number)
{
  if (number < 0 || number > 9)
    return 0x00;
  return _numbers[number];
}
uint8_t TM1637::getCharacter(char character)
{
  character = tolower(character);

  if (isAlpha(character))
    return _alphabet[(character - 97)];
  if (isDigit(character))
    return _numbers[(character - 48)];

  switch (character)
  {
    case '-':
      return _segments[6];
    case '.':
      return _segments[7];
    case '_':
      return _segments[3];
    case ',':
      return _specialCharacters[0];
    case '!':
      return _specialCharacters[1];
    case '?':
      return _specialCharacters[2];
    case '=':
      return _specialCharacters[3];
    case '>':
      return _specialCharacters[4];
    case '<':
      return _specialCharacters[5];
    case '(':
      return _specialCharacters[6];
    case ')':
      return _specialCharacters[7];
    case '/':
      return _specialCharacters[8];
    case '*':
      return _specialCharacters[9];
    case '"':
      return _specialCharacters[10];
    case '^':
      return _specialCharacters[11];
  }

  return 0x00;
}


bool TM1637::digitInRange(int8_t digit)
{
  return 0 <= digit && digit < DISPLAY_LENGTH;
}
bool TM1637::segmentInRange(int8_t segment)
{
  return 0 <= segment && segment < 8;
}


void TM1637::start()
{
  pinMode(_pinDIO, OUTPUT); // pull dio low: indicate data input
  writeDelay();
}
void TM1637::stop()
{
  pinMode(_pinDIO, OUTPUT); // keep dio low for one clk pulse
	writeDelay();

	pinMode(_pinCLK, INPUT); // clk high
	writeDelay();
	pinMode(_pinDIO, INPUT); // dio high
	writeDelay();
}
bool TM1637::writeByte(uint8_t data)
{
  // write byte to tm1637 via two-wire-interface
  uint8_t pointer = 1;
  for (uint8_t i = 0; i < 8; i++)
  {
    pinMode(_pinCLK, OUTPUT); // clk pulse low
    writeDelay();

    pinMode(_pinDIO, (data & pointer) > 0 ? INPUT : OUTPUT); // write bit on dio
    writeDelay();

    pinMode(_pinCLK, INPUT); // clk pulse high
    writeDelay();

    pointer = pointer << 1; // move to next bit pointer
  }

  // wait for ack, dio high (pulled down by tm1637)
  pinMode(_pinCLK, OUTPUT);
  pinMode(_pinDIO, INPUT);
  writeDelay();

  pinMode(_pinCLK, INPUT); // clk pulse high
  writeDelay();

  // read ack signal
  uint8_t ack = digitalRead(_pinDIO);
  if (ack == 0)
    pinMode(_pinDIO, OUTPUT);
  writeDelay();

  pinMode(_pinCLK, OUTPUT);
  writeDelay();

  return ack;
}
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

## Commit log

2025-11-25 added PCB version 3
    [BOM_GeigerMuellerMainBoard_V3.csv, PickAndPlace_GeigerMuellerMainBoard_V3.csv]
2025-11-25 added version 3 schematic
